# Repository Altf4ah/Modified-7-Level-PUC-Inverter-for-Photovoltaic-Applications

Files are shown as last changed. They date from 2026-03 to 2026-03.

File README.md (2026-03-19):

# Modified 7-Level PUC Inverter for Photovoltaic Applications

## Overview

This repository presents the design, simulation, and hardware implementation of a **Modified Seven-Level Packed U-Cell (MPUC) Inverter** for photovoltaic applications.

Multilevel inverters are widely used in renewable energy systems to convert DC power generated by solar panels into high-quality AC power suitable for loads or grid integration. Traditional inverter topologies such as Cascaded H-Bridge and Neutral Point Clamped inverters often require a large number of switches and components.

The **Modified Packed U-Cell (MPUC) inverter** provides a compact and efficient alternative by generating multiple voltage levels using fewer components while maintaining high power quality.

This project demonstrates both:

- Simulation validation of the proposed inverter topology
- Hardware implementation of a scaled prototype

---

# Project Objectives

The main objectives of this project are:

- Design a **Modified 7-Level PUC inverter topology**
- Implement **multicarrier SPWM control strategy**
- Validate the system through **simulation**
- Develop a **scaled hardware prototype**
- Analyse output voltage waveform and harmonic distortion

---

# Inverter Topology

The Modified PUC inverter is a **seven-level multilevel inverter topology** that uses:

- Two asymmetrical DC voltage sources
- Six switching devices
- A specialised switching sequence

The topology produces the following output voltage levels:

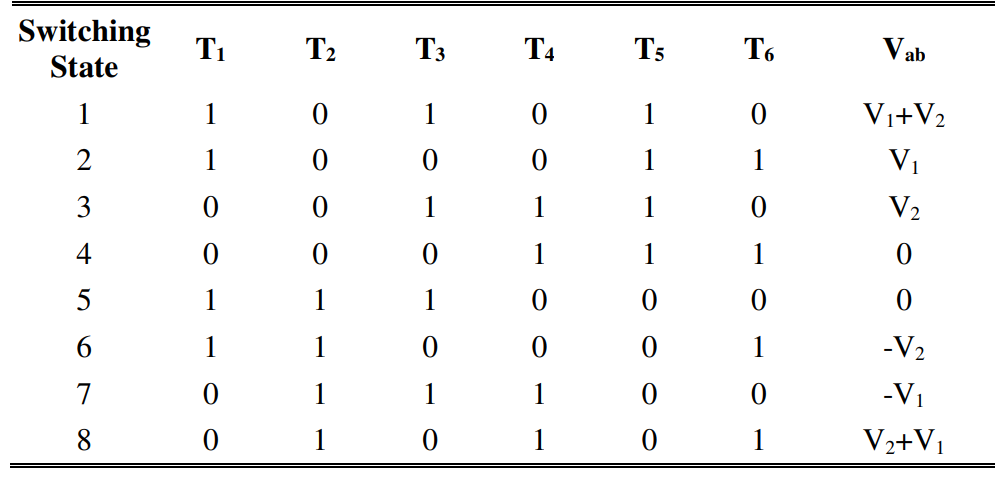
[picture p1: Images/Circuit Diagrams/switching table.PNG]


This multilevel output closely approximates a sinusoidal waveform, reducing harmonic distortion and improving power quality.

---

# Phase 1 — Simulation

The simulation phase validates the proposed inverter design before hardware implementation.

### Tools Used

- MATLAB
- Simulink

### Simulation Components

- MPUC inverter topology
- Multicarrier SPWM generation
- Switching algorithm
- Harmonic analysis

### Simulation Outputs

- 7-level output voltage waveform
- Load current waveform
- FFT analysis
- Total Harmonic Distortion (THD)

---

# Phase 2 — Hardware Implementation

A scaled hardware prototype was developed to validate the inverter performance.

### Hardware Modules

The hardware system consists of three main modules:

### 1. Power Supply Module

- Custom multi-tap transformer
- Bridge rectifier
- Filtering capacitors
- Provides isolated power for gate drivers

### 2. Driver Module

- Optocoupler-based isolation
- Gate driver circuits
- Signal amplification for MOSFET switching

### 3. Inverter Module

- Six MOSFET switches
- Two DC voltage sources
- Converts DC input into multilevel AC output

---

# Hardware Specifications

| Parameter | Value |
|---|---|
| Output Voltage | 45 V |
| Output Current | 1 A |
| Switching Devices | IRF540N MOSFET |
| Control Unit | Arduino |
| Driver IC | TLP350 |

---

# Control Strategy

The inverter switching signals are generated using an **Arduino-based control system** implementing a predefined switching table.

This generates the required sequence to produce the **seven-level output waveform**.

---

# PCB Design

The inverter and driver circuits were designed and implemented using:

- PCB layout design
- Copper board etching using ferric chloride
- Component soldering and testing

---

# Results

The results demonstrate that the Modified PUC inverter can generate a multilevel AC waveform with improved quality compared to conventional inverters.

Key outcomes:

- Successful generation of **7-level output voltage**
- Reduced harmonic distortion
- Efficient DC-AC conversion
- Successful hardware validation

---

# Applications

This inverter topology can be applied in:

- Solar photovoltaic systems
- Renewable energy converters
- Microgrid power systems
- Grid-connected inverter systems

---

## Repository Structure

- **Simulation/**
  - MATLAB / Simulink models

- **Hardware/**
  - Driver circuits
  - Inverter circuit
  - PCB design files

- **Arduino_Code/**
  - Switching control program

- **Images/**
  - Circuit diagrams
  - Simulation results
  - Hardware output waveforms

- **Documentation/**
  - Final project report
  - Presentation slides
---

# Authors

Final Year B.Tech Project.  
Department of Electrical Engineering.  
Govt. Model Engineering College, Thrikkakara.

- Althaf Ahmed   
- Daniel Charles  
- Aswathy V  
- Shaun George

---

# License

This project is published for **academic and research purposes**.

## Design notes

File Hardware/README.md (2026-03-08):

KiCad PCB project for a PUC inverter along with its driver board, designed as a single-layer layout and optimized for DIY etching.

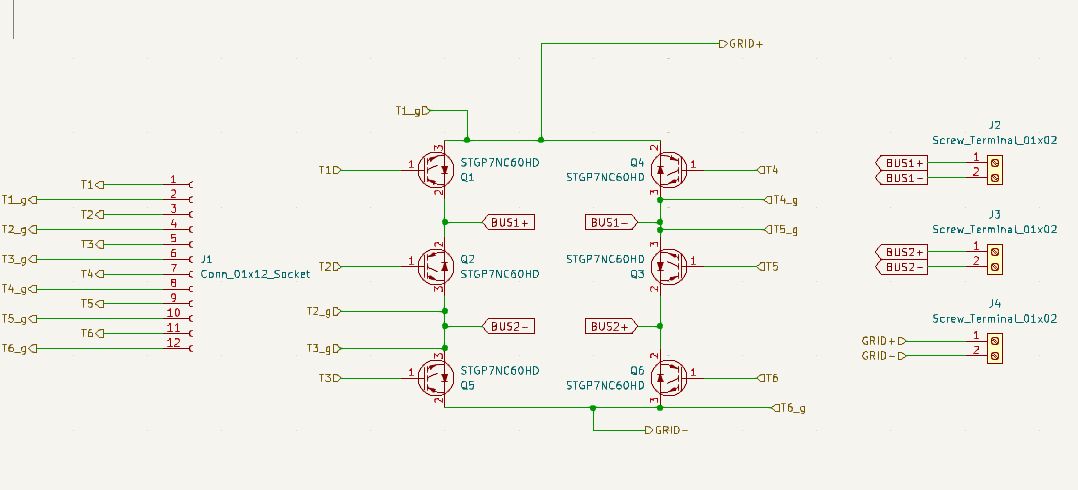
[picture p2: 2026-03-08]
Images/Circuit Diagrams/inverter_schematic.png

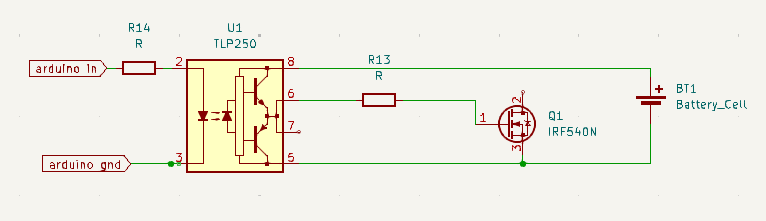
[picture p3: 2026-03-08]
Images/Circuit Diagrams/schematic 1.png

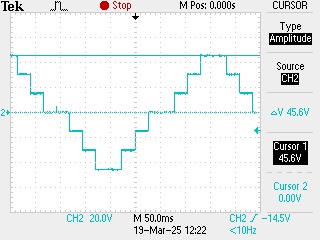
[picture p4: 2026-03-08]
Images/Hardware output waveform/out1.jpg

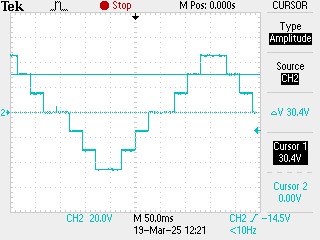
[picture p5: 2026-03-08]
Images/Hardware output waveform/out3.jpg

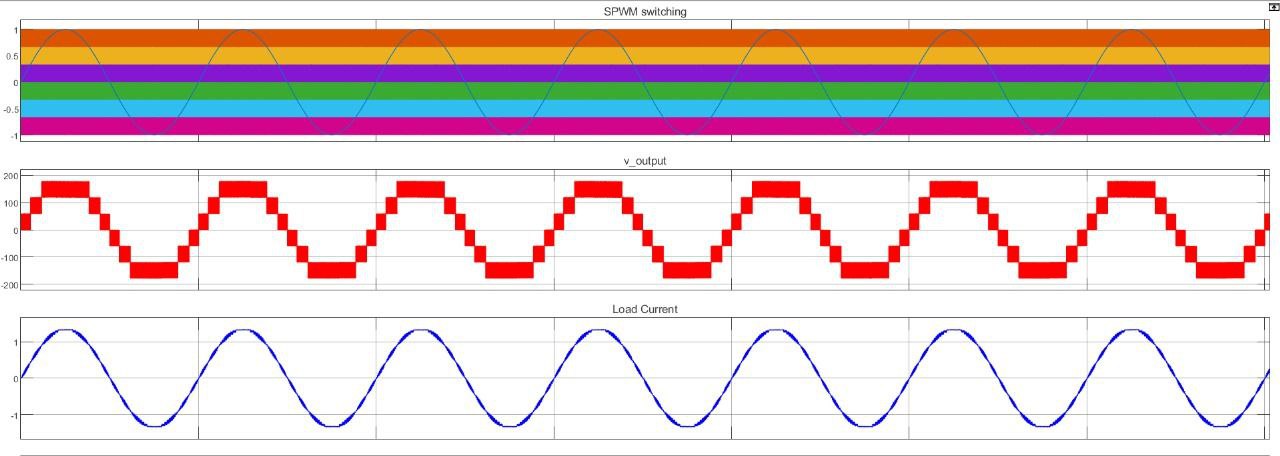
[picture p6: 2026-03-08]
Images/Hardware output waveform/oploopgraph.jpg

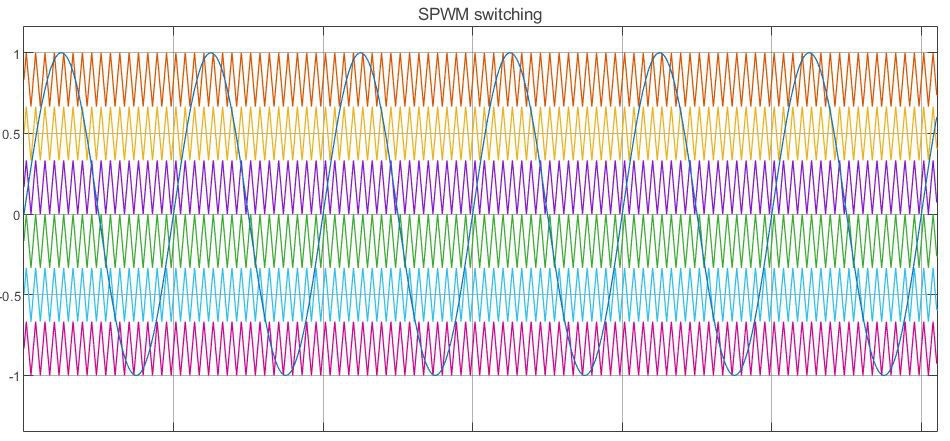
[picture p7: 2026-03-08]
Images/Hardware output waveform/sinepwm.jpg

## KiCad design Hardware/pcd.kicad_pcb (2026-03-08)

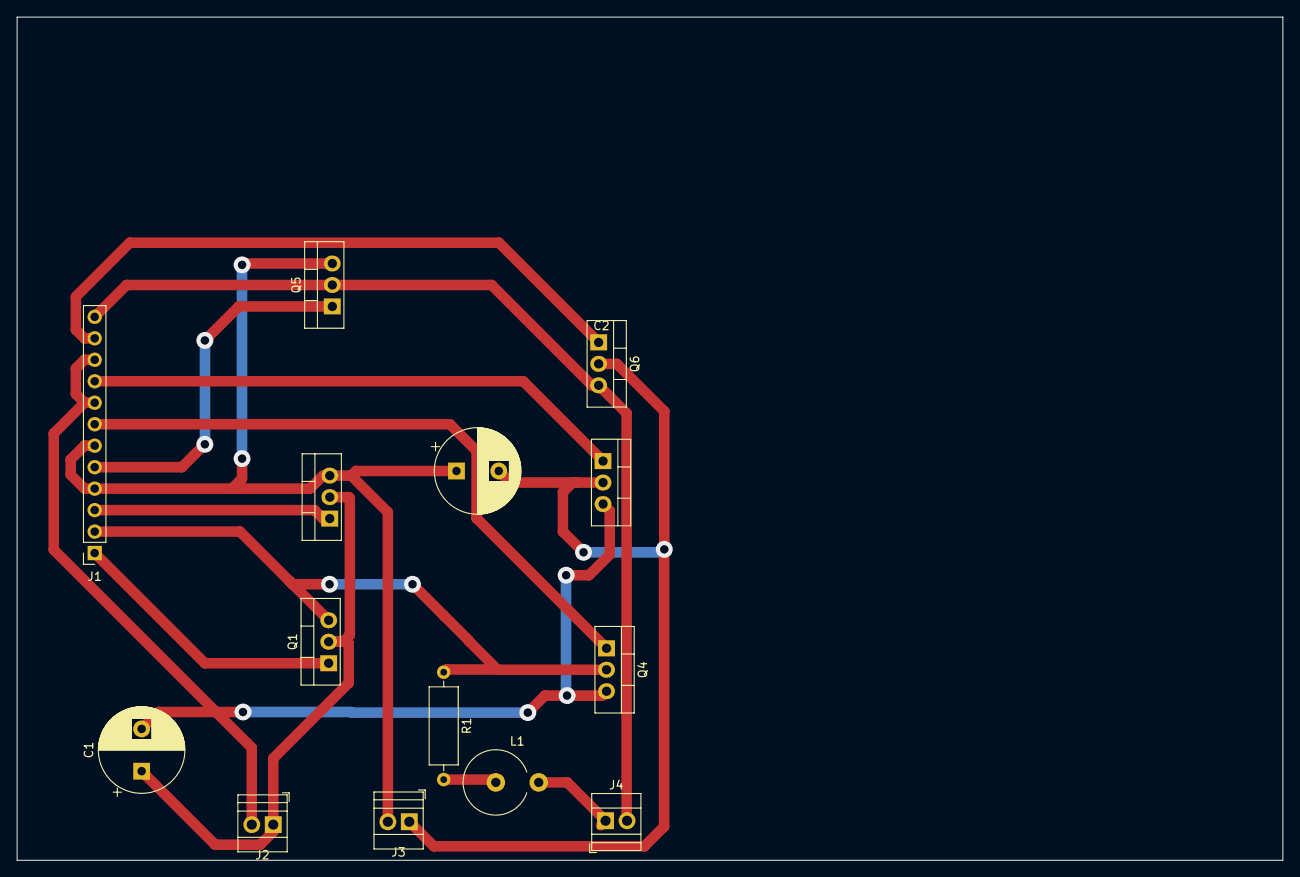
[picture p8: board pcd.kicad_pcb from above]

Board: 2 copper layers, 149.7 x 99.7 mm, 14 parts (0 on the bottom side), 14 nets.

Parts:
C1, C2: C; CP_Radial_D10.0mm_P5.00mm
J1: Conn_01x12_Socket; PinSocket_1x12_P2.54mm_Vertical
J2, J3, J4: Screw_Terminal_01x02; TerminalBlock_Xinya_XY308-2.54-2P_1x02_P2.54mm_Horizontal
L1: L; L_Axial_L16.0mm_D7.5mm_P5.08mm_Vertical_Fastron_XHBCC
Q1, Q2, Q3, Q4, Q5, Q6: STGP7NC60HD; TO-220-3_Vertical
R1: R; R_Axial_DIN0309_L9.0mm_D3.2mm_P12.70mm_Horizontal

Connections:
/GRID+: J4.1, L1.2
/GRID-: J1.12, J4.2, Q5.2 (C), Q6.3 (E)
/T1: J1.1, Q1.1 (G)
/T1_g: J1.2, Q1.3 (E), Q4.2 (C), R1.1
/T2: J1.3, Q2.1 (G)
/T3: J1.5, Q5.1 (G)
/T4: J1.7, Q4.1 (G)
/T5: J1.9, Q3.1 (G)
/T6: J1.11, Q6.1 (G)
BUS1+: C1.1, J2.1, Q1.2 (C), Q2.2 (C)
BUS1-: C1.2, J1.8, J1.10, J2.2, Q3.3 (E), Q4.3 (E)
BUS2+: C2.2, J3.1, Q3.2 (C), Q6.2 (C)
BUS2-: C2.1, J1.4, J1.6, J3.2, Q2.3 (E), Q5.3 (E)
unnamed: L1.1, R1.2

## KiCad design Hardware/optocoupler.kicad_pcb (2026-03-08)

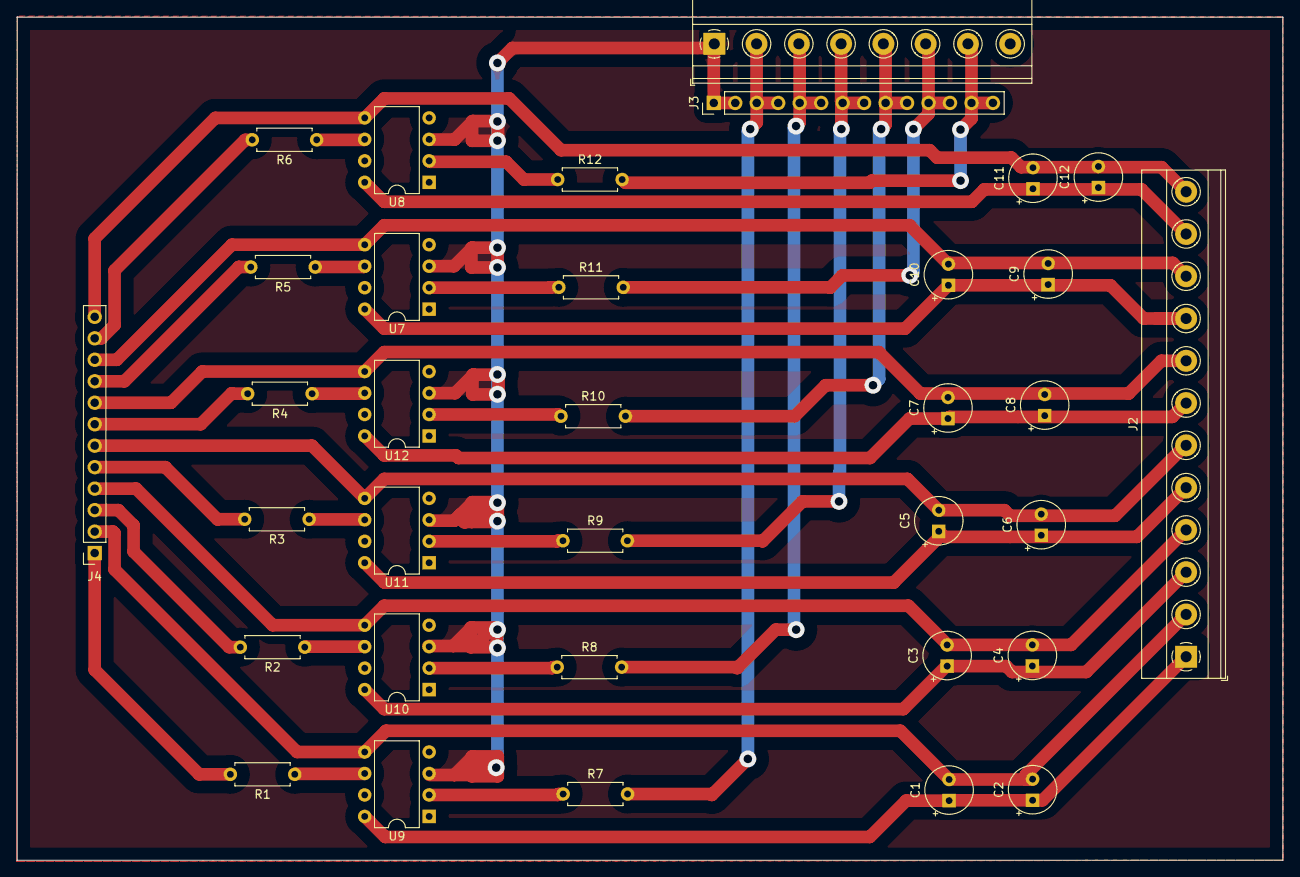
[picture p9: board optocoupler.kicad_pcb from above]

Board: 2 copper layers, 149.7 x 99.7 mm, 34 parts (0 on the bottom side), 37 nets.

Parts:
C1, C2, C3, C4, C5, C6, C7, C8, C9, C10, C11, C12: C; CP_Radial_Tantal_D5.5mm_P2.50mm
J1: Screw_Terminal_01x07; TerminalBlock_Phoenix_MKDS-1,5-8_1x08_P5.00mm_Horizontal
J2: Conn_01x12_Socket; TerminalBlock_Phoenix_MKDS-1,5-12_1x12_P5.00mm_Horizontal
J3: Screw_Terminal_01x14; PinHeader_1x14_P2.54mm_Vertical
J4: Conn_01x12_Socket; PinSocket_1x12_P2.54mm_Vertical
R1, R2, R3, R4, R5, R6, R7, R8, R9, R10, R11, R12: R; R_Axial_DIN0207_L6.3mm_D2.5mm_P7.62mm_Horizontal
U7, U8, U9, U10, U11, U12: TLP250; DIP-8_W7.62mm

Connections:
/T1: R1.1, U9.6 (VO)
/T1_g: C1.2, C2.2, J2.2, J4.2, U9.5 (VEE)
/T1_i: J1.2, J3.3, J3.4, R7.2
/T2: R2.1, U10.6 (VO)
/T2_g: C3.2, C4.2, J2.4, J4.4, U10.5 (VEE)
/T2_i: J1.3, J3.5, J3.6, R8.2
/T3: R3.1, U11.6 (VO)
/T3_g: C5.2, C6.2, J2.6, J4.6, U11.5 (VEE)
/T3_i: J1.4, J3.7, J3.8, R9.2
/T4: R4.1, U12.6 (VO)
/T4_g: C7.2, C8.2, J2.8, J4.8, U12.5 (VEE)
/T4_i: J1.5, J3.9, J3.10, R10.2
/T5: R5.1, U7.6 (VO)
/T5_g: C9.2, C10.2, J2.10, J4.10, U7.5 (VEE)
/T5_i: J1.6, J3.11, J3.12, R11.2
/T6: R6.1, U8.6 (VO)
/T6_g: C11.2, C12.2, J2.12, J4.12, U8.5 (VEE)
/T6_i: J1.7, J3.13, J3.14, R12.2
/s1_i: C1.1, C2.1, J2.1, U9.8 (VCC)
/s2_i: C3.1, C4.1, J2.3, U10.8 (VCC)
/s3_i: C5.1, C6.1, J2.5, U11.8 (VCC)
/s4_i: C7.1, C8.1, J2.7, U12.8 (VCC)
/s5_i: C9.1, C10.1, J2.9, U7.8 (VCC)
/s6_i: C11.1, C12.1, J2.11, U8.8 (VCC)
GNDD: J1.1, J3.1, J3.2, U7.3 (C), U8.3 (C), U9.3 (C), U10.3 (C), U11.3 (C), U12.3 (C)
unnamed: J4.1, R1.2
unnamed: J4.3, R2.2
unnamed: J4.5, R3.2
unnamed: J4.7, R4.2
unnamed: J4.9, R5.2
unnamed: J4.11, R6.2
unnamed: R11.1, U7.2 (A)
unnamed: R12.1, U8.2 (A)
unnamed: R7.1, U9.2 (A)
unnamed: R8.1, U10.2 (A)
unnamed: R9.1, U11.2 (A)
unnamed: R10.1, U12.2 (A)

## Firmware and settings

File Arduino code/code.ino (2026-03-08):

module switching(
    input wire s1, s2, s3, s4, s5, s6, s7, s8,
    output reg t1, t2, t3, t4, t5, t6
);
    


    
        parameter state0 = 6'b101010,
                state1 = 6'b100011,
                state2 = 6'b001110,
                state3 = 6'b000111,
                state4 = 6'b111000,
                state5 = 6'b110001,
                state6 = 6'b011100,
                state7 = 6'b010101;
    
    

    wire [7:0] state_mat;
    assign state_mat = {s1, s2, s3, s4, s5, s6, s7, s8};
    
    always @(*) begin
        case (state_mat)
            8'b10000000: {t1, t2, t3, t4, t5, t6} = state0;
            8'b01000000: {t1, t2, t3, t4, t5, t6} = state1;
            8'b00100000: {t1, t2, t3, t4, t5, t6} = state2;
            8'b00010000: {t1, t2, t3, t4, t5, t6} = state3;
            8'b00001000: {t1, t2, t3, t4, t5, t6} = state4;
            8'b00000100: {t1, t2, t3, t4, t5, t6} = state5;
            8'b00000010: {t1, t2, t3, t4, t5, t6} = state6;
            8'b00000001: {t1, t2, t3, t4, t5, t6} = state7;
            default: {t1, t2, t3, t4, t5, t6} = 6'b000000;
        endcase
    end
endmodule

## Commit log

2026-03-08 PCB design
    [optocoupler.kicad_pcb, optocoupler.kicad_sch, pcd.kicad_pcb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]
2026-03-08 switching code
2026-03-08 Circuit diagram
2026-03-19 oltage Updates
    Removed voltage level output table from README.
2026-03-19 Voltage updaged
